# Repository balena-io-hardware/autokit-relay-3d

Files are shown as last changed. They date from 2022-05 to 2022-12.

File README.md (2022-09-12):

# Automation kit usb relay

This repo contains the files needed to source components and assemble the USB relay device that is to be used as part of the automation kit suite. 

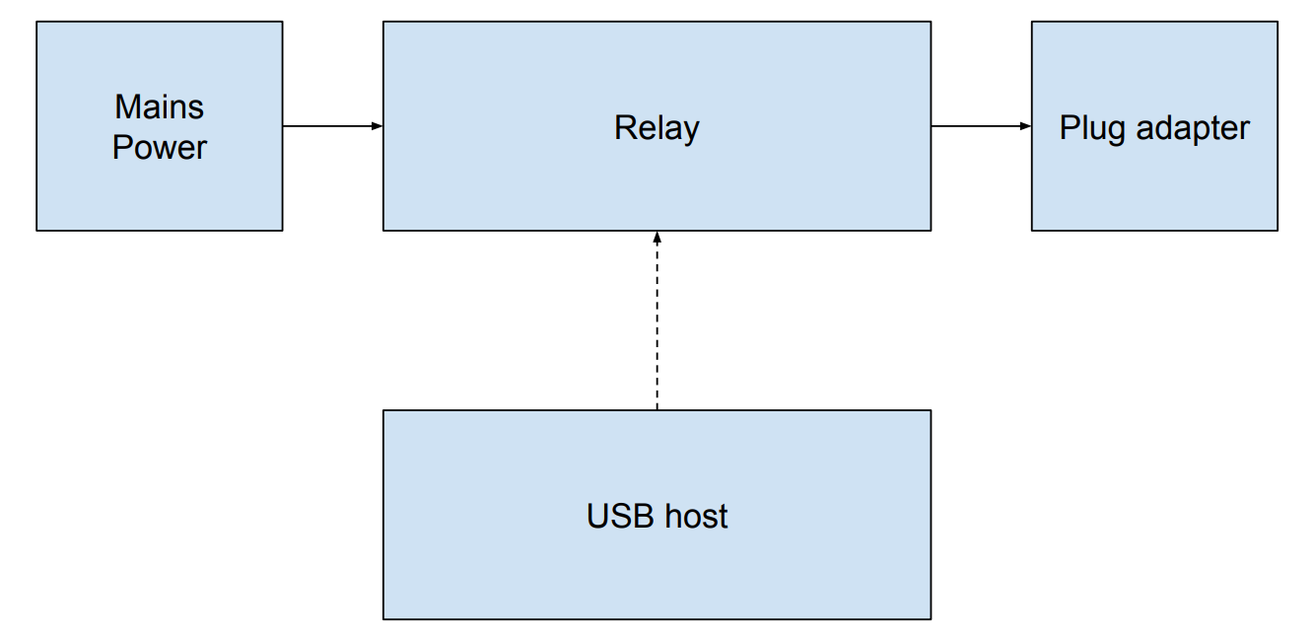
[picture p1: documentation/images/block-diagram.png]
Block diagram


The device is built around an off the shelf USB relay, with an enclosure built around it for both safety and ease of use.

To control the USB relay, the following tool can be used: https://github.com/darrylb123/usbrelay
The quickest way to use it is to install the package:

```
sudo apt-get install usbrelay
```

Check your device's serial number:

```
sudo usbrelay
```

Example output:

```
root@a6a7c99:/usr/src/app# usbrelay HURTM_1=0
Orig: HURTM, Serial: HURTM, Relay: 1 State: fd
Device Found
  type: 16c0 05df
  path: /dev/hidraw0
  serial_number:
  Manufacturer: www.dcttech.com
  Product:      USBRelay2
  Release:      100
  Interface:    0
  Number of Relays = 2
Serial: HURTM, Relay: 1 State: fd
1 HID Serial: HURTM Serial: HURTM, Relay: 1 State: fd

Serial: HURTM, Relay: 1 State: fd --- Found
```

And then toggle it with:
```
sudo usbrelay HURTM_1=0
```

## Capabilities

- Toggle mains power via USB

## Interface

### Hardware

- C14 power input to connect to mains
- C13 output to connect to plug adapter for country/region its being used in
- USB B to connect to the host that will control the relay

### Software

- Open source control library: https://github.com/darrylb123/usbrelay
- Enables command line control, or Python library

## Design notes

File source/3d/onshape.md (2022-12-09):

# Modifying the source design using Onshape

The design was created using [Onshape](https://www.onshape.com/en/) which is a cloud based cad platform.

The current version of the design can be accessed [here](https://cad.onshape.com/documents/c4bc9ea6837673c88c941446/v/211e8d346dc0e6cd899853e4/e/98419725be3989dcd2e71b74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)

This will link to a version of the design.

## Creating a new version

In Onshape, select the option to create a new version. Then update the link in the `./specification/spec.json` to the new version you just created.

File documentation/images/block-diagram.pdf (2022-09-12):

Relay Mains
Power | Plug adapter

USB host

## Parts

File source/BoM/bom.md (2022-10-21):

# Bill of materials

| Part | quantity | link 1 |
|---|---|---|
| USB relay | 1 | https://www.amazon.de/-/en/ARCELI-SRD-05VDC-SL-C-Module-Control-Intelligent/dp/B07JL4YB8R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 |
| 3D printed enclosure | 1 | (repo) |
| C13 to plug socket adapter | 1 | https://cpc.farnell.com/pro-power/pel01253/iec-c14-plug-to-13a-socket-black/dp/PL15014 |
| Insulated cable 2.5mm² (brown) |  2x 8cm | Local |
| Insulated cable 2.5mm² (blue) | 2x 8cm | Local |
| Insulated cable 2.5mm² (green/yellow) |  12cm | Local |
| Screws M2.5x8mm Countersunk **(only if using screw-on C13/C14 connectors)** | 4 |  Local |
| Screws M2.5x8mm Countersunk | 6 |  Local |
| Power entry module C13 | 1 | https://www.mouser.co.uk/ProductDetail/Schurter/6600.4325?qs=wwP%252BWDYHj0ZPX21Cb5C%252B0w%3D%3D |
| Power entry module C14 | 1 | https://www.mouser.co.uk/ProductDetail/Schurter/6100.4325?qs=wwP%252BWDYHj0YjN4UVrUCMAw%3D%3D |
| Insulated blue quick connect terminals 6.4x0.8mm | 6 | https://cpc.farnell.com/pro-power/stfdfd2-250-10/female-push-on-terminals-blue/dp/CN11431?mckv=s_dc\|pcrid\|426684131039\|kword\|\|match\|\|plid\|\|slid\|\|product\|CN11431\|pgrid\|100371158878\|ptaid\|pla-1252988897717\|&CMP=KNC-GUK-CPC-SHOPPING&s_kwcid=AL!5616!3!426684131039!!!network}!1252988897717!&gclid=CjwKCAjw4ayUBhA4EiwATWyBrvZNPg9RGUUbJMV9b9xapA4t2o8Dei9Cu2NZsWDB-BcycAaNYZI2ZhoCbJIQAvD_BwE |

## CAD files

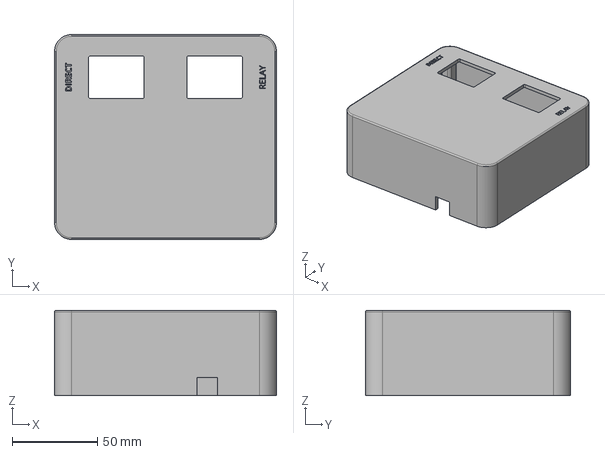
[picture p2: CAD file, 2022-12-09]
output/Top.step
130.0 x 120.0 x 50.0 mm

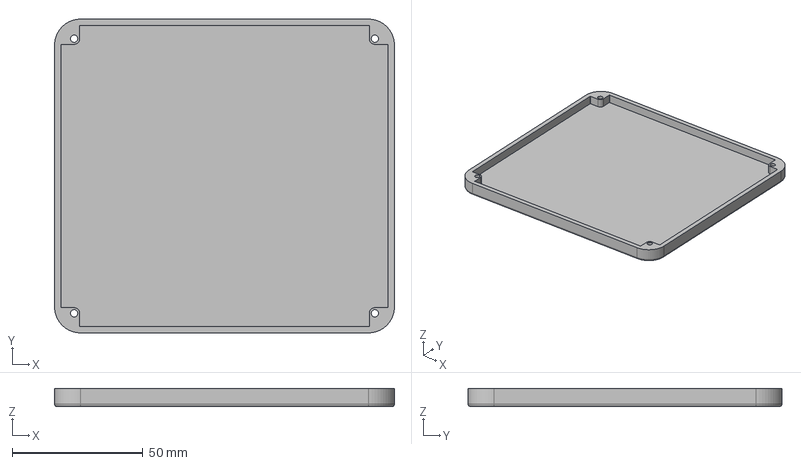
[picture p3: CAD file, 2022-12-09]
output/Bottom.step
130.0 x 120.0 x 7.00 mm

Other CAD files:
output/Bottom.stl
output/Top.stl

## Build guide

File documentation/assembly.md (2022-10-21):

# Assembly guide

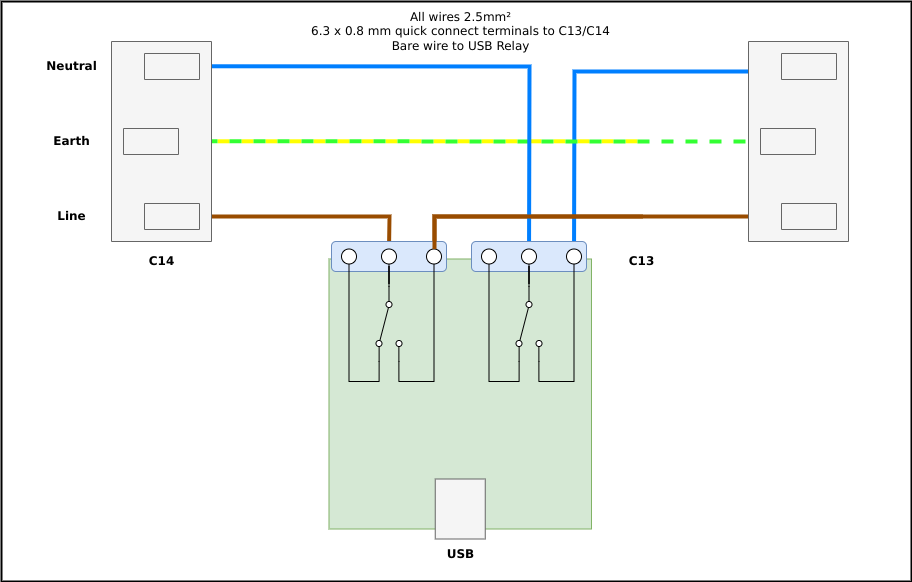
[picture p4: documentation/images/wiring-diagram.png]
Wiring diagram


1. Mount the relay in the bottom half of the case
2. Prepare 6 strands of the unsulated cable, 2 blue, 2 brown, 1 yellow/green
3. Crimp fast release terminals to both ends of the  yellow/green wires
4. Crimp fast release terminals to one end of each of the brown and blue wires
5. Screw the bare wire terminals into the NC and COM terminals of the relay according to the diagram
7. Attach the fast release terminals to the C13 and C14 connectors
9. Place the C13/14 connectors in the right size holes that are cut into the case
10. Place the top half of the case on top of the bottom half

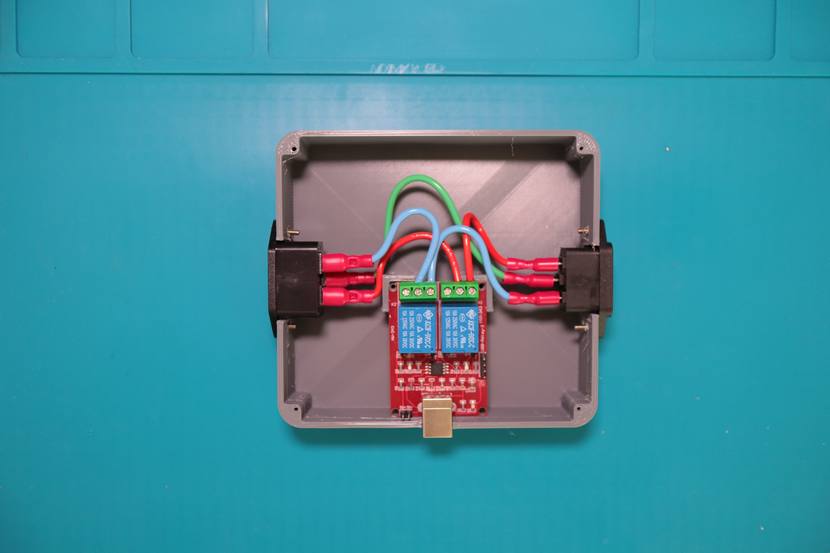
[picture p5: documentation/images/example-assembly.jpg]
Example assembly


> **Note:** The above image didn't use the correct colors as electrical wiring standards vary depending on the country. Thus, it should only be used as a reference. Further builds must use the colors indicated in the textual description above.

> **Note:** If the relay board feels flimsy inside the case you may use M2.5x6mm screws to hold it in place

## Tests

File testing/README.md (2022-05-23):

# Testing

In this folder, you have to add atleast one file - `Testing.md`.  Here you will pass instructions to the Prototyping Lab about functional, and other kinds of testing for your prototype. See some examples of this file on [the docs page](https://landr-balena-io-hardware-repo-hardware-process.netlify.app/docs/add-testing-instructions)

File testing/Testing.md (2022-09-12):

# Test instructions

## Test 1 - mechanical test

- Success
  - Case assembles correctly
  - All connectors are snug with the case
- Failure
  - Top and bottom half of case are not aligned
  - Top and bottom half of case are not connected without a gap
  - C13/14 connectors do not fit without a gap

## Test 2 - Functionality test

- Setup
  - Connect the device to a mains supply
  - Connect the output to a C13 to plug socket adapter
  - Plug a Raspberry Pi in to the plug socket with its power adapter
  - Plug the relay into a Linux device via USB
  - Ensure that the relay driver is installed on the host device: `sudo apt-get install usbrelay`
  - Find out your device serial number with `sudo usbrelay`
  - Run `sudo usbrelay $YOUR_SERIAL=1`

- Success
  - The Raspberry Pi powers on
- Failure
  - The Raspberry Pi doesn't power on

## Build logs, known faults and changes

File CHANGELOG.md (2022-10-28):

# Change Log

All notable changes to this project will be documented in this file
automatically by Versionist. DO NOT EDIT THIS FILE MANUALLY!
This project adheres to [Semantic Versioning](http://semver.org/).

# v1.1.0
## (2022-10-28)

* Convert to Flowzone [Pedro Henrique Kopper]

# v1.0.0
## (2022-10-21)

* Add double relay support [Pedro Henrique Kopper]
* Changed box layout to fit double relay board [Pedro Henrique Kopper]

# v0.1.0
## (2022-08-24)

* case design update [konmouz]
* Remove extra output files [Pedro Henrique Kopper]
* Add initial files and documentation [rcooke-warwick]

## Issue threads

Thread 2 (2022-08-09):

Use DPDT relay to comply with safety standards

phckopper, 2022-08-09:
> @rcooke-warwick, @phckopper
> For production will be good to use a DPDT relay that can cut off both AC phases (L&N). In this case use terminals with pitch 7.62mm to be compatible with safety standards.

_Originally posted by @zisis00 in https://github.com/balena-io-hardware/autokit-relay-3d/issues/1#issuecomment-1209229712_

rcooke-warwick, 2022-08-22:
recommended to use this one

https://www.amazon.de/-/en/ARCELI-SRD-05VDC-SL-C-Module-Control-Intelligent/dp/B07JL4YB8R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

Closed 2022-10-28.

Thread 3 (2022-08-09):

Use power entry modules for PCB

phckopper, 2022-08-09:
> Also, you can use power entry modules for pcb to avoid the cables and the friction during assembly and sourcing, for example:https://www.amazon.com/Power-Entry-Modules-Mount-piece/dp/B00M1K8216. In this case the pcb should be larger and re-design the case to match the height. I think it worth as the total cost and the complexity are less.

_Originally posted by @zisis00 in https://github.com/balena-io-hardware/autokit-relay-3d/issues/1#issuecomment-1209229712_

rcooke-warwick, 2023-01-17:
as we are not using a custom relay PCB, I think we can close this issue for now

Closed 2023-01-17.

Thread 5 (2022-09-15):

Transfer Skadis mounting holes to the other part of the case

phckopper, 2022-09-15:
As per @konmouz suggestion, transfer the Skadis mounting holes to the thinner plate, in order to block access to the screws while the relay is mounted to the board.

[Internal link](https://jel.ly.fish/2c6cdee5-d283-46ff-ada1-77972ac5934c?event=e4e97518-b52f-47b8-84c5-ffc88462176a)

Closed 2022-10-28.

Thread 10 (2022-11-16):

C13 & C14 connectors should be shifted 5mm away from the relay board

Bucknalla, 2022-11-16:
In v1.1.0 the C13 and C14 connectors should be shifted further away from the relay board to improve the angle at which cables are routed into the relay board. Currently it is too steep and causes the cables to bend at 90 degrees.

rcooke-warwick, 2023-01-17:
will be resolved by https://github.com/balena-io-hardware/autokit-relay-3d/pull/12

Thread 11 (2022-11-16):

Increase the vertical height of the lid to the case

Bucknalla, 2022-11-16:
In v1.1.0 we need to increase the height of the lid (~2-3mm) as it collides with the relays on the double relay board, causes some flexing.

rcooke-warwick, 2023-01-17:
may be resolved by https://github.com/balena-io-hardware/autokit-relay-3d/pull/12

anujdeshpande, 2023-02-08:
Faced the same issue

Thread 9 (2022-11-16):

Add clearance for relay soldered pads under the connection terminals

Bucknalla, 2022-11-16:
In v1.1.0 there is not enough clearance for the feet of the double relay soldered pads, under the connection terminals, to allow for the relay board to sit flush on the bracket. Please add some clearance to allow for the soldered pads.

rcooke-warwick, 2023-01-17:
will be resolved by https://github.com/balena-io-hardware/autokit-relay-3d/pull/12

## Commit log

2022-08-11 Add initial files and documentation
    fix diagram and update design based on prototype
    Update commands to consider serial number
    Point link to new CAD design
    Update testing instructions
    Update spec.json to new CAD link
    Add assembly instructions
    Misc proofreading
    Update BoM
    Fix README.md block diagram
    Change-type: minor
    [relay-botom-half.stl, relay-top-half.stl, relay.step]
2022-08-11 Remove extra output files
    Change-type: patch
    [relay-botom-half.stl, relay-top-half.stl, relay.step]
2022-08-18 case design update
    - Reduced the overall size of the case
    - Reduced the size of the C13/C14 holes - the screw can self thread
    - Made an opening under the PCB for the solder pins to not collide with the case
    - The bottom part is designed to push the relay against the top part and lock it in place with no screws
    - Added 4 pegs at the bottom for alignment with the top
    - Changed the top and bottom corner radiuses so it prints without support reliably
    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
    [Case - Bottom.step, Case - Bottom.stl, Case - Top.step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]
2022-08-24 case design update
    - Increased width for better strain relief
    - Added Skadis mounting tabs
    - Increased screw-on connector hole size to 2mm
    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
    [Case - Bottom.step, Case - Bottom.stl, Case - Top.step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]
2022-09-16 Changed box layout to fit double relay board
    * Widened PCB support to allow fitting the larger board (#2)
    * Widened the box itself to ease wiring
    * Moved Skadis mounting holes to bottom part (#5)
    Change-type: major
    [Case - Bottom.step, Case - Bottom.stl, Case - Top.step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]
2022-10-21 Add double relay support
    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
2022-10-28 Convert to Flowzone
    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
2022-12-09 Dual power out
    - Added a direct power out
    - Moved both power out ports on the top surface
    - Added more height
    - Moved USB
    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
2022-12-09 Added 3d files
    [Bottom.step, Bottom.stl, Top.step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]
